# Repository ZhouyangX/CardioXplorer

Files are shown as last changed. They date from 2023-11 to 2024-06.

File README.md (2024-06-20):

# CardioXplorer: An Open-Source Catheter Robot

This repository contains open-source resources for a modular robotic system, designed for catheter ablation procedures, and validated by trainees and cardiologists. However, the modular design of the robot encourages the application of the system in various fields requiring the use of catheters.

Please make sure to reference or acknowledge the use of our repository if you find it useful!

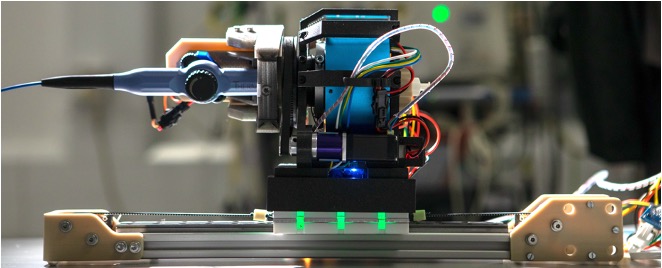
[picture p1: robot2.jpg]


## Overview

The robot is designed to manipulate commercial catheters in 3 degrees of freedom (DoF):
- Axial insertion/retraction
- Tool shaft rotation
- Catheter tip articulation

Independent actuators were employed for each DoF to enable flexible reconfiguration. The handle interface is easily customizable using silicone molds, thus able to accommodate various commercial catheters.

## Content

The repository contains:
- **CAD models** - 3D design files for mechanical parts.
- **Catheter Library** - 3D design files for 3 commercial catheter handles for ablation therapy and corresponding design files to develop silicone inserts for knob-based actuation module.
- **Software** - Control code, simulation (Blender Python API), data logger.
- **Media** - Photos and diagrams of the robot and the electronics.
- **Clincal Feedback** - Questionnaire and feedback results.

## Getting Started

To build the robot system:
1. 

| Part | Quantity | Estimated Cost |
| --- | --- | -- |
| PLA 3D Printer Filament | 1kg | $20 |
| PETG 3D Printer Filament | 50g | $5 |
| TPU 3D Printer Filament | 50g | $5 |
| Nema 17 Stepper Motor | 1 | $50 |
| Nema 8 Stepper Motor w/ 19:1 Gearbox | 1 | $50 |
| SAVOX SC-1251 MG 9kg Servo | 1kg | $50 |
| 6ch Through-hold Slip Ring | 1kg | $50 |
| 3mm Aluminum Plate | 1kg | $5 |
| 38.1mm OD Aluminum Pipe | 0.5m | $5 |
| WS2812B Addressable LEDs | 1m | $15 |
| 12V Electromagnets | 5 | $30 |
| Limit Switches | 2 | $2 |
| 20T GT2 Gears | 2 | $5 |
| 208T GT2 Close Loop Belt | 1 | $5 |
| GT2 Belt | 0.8m | $5 |
| Arduino MKR Zero | 4 | $130 |
| Arduino CAN Bus Shield | 4 | $130 |
| Arduino RS485 Shield | 2 | $50 |
| PS5 Controller | 1 | $30 |
| Mil-Max Pogo Connectors Pair | 1 | $5 |
| Hall Effect Sensor w/ Magnets | 1 | $10 |
| TMC5160 Stepper Motor Driver | 2 | $30 |
| **Estimated Total Cost:** | **-** | **$687** |

## Publications
The design and validation are described in the following publication:

Reference article - [https://doi.org/10.3390/robotics13050080](https://doi.org/10.3390/robotics13050080)

Xu, Z., Zeidan, A. M., He, Y., Leung, L., Byrne, C., Sabu, S., ... & Rhode, K. (2024). CardioXplorer: An Open-Source Modular Teleoperative Robotic Catheter Ablation System. Robotics, 13(5), 80.

## License
The contents of this repository are made available under the CC License. See LICENSE for details.

## Contributing
We welcome contributions - please submit pull requests!
See CONTRIBUTING for guidelines.

## Contact
Contact the team by email with any questions.

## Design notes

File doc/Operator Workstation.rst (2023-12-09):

Operator Workstation setup
======================

The operator workstation consist of two parts (MCU-based Controller and Display Unit).

MCU-Based Controller
--------------------------

This requires the installation of `Bluepad32 for Arduino <https://github.com/ricardoquesada/bluepad32-arduino>`_ firmware on the uBlox32 (or NINA) before uploading the Arduino code.

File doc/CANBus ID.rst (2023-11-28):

CANBus Message Table
======================

The CardioXplore uses a series of CANBus messages to communicate with other modules, all messages are sent at 1Mbps and with 8 bytes in each message.

CANBus Message Information
--------------------------
.. list-table::
   :widths: 25 50
   :header-rows: 1

   * - CANBus ID
     - Information
   * - 0x10
     - Joystick Controller
   * - 0x20
     - Railing Responder
   * - 0x30
     - Rotation Responder

Message Breakdown
------------------
.. list-table:: CANBus0x10
   :widths: 25 50
   :header-rows: 1

   * - Byte Position
     - Messages
   * - 0 
     - Left Joystick - X movement
   * - 1
     - Left Joystick - Y movement
   * - 2
     - Right Joystick - X movement
   * - 3
     - Right Joystick - Y movement
   * - 4
     - Right Joystick - R3 Button
   * - 5
     - L1 Button
   * - 6
     - R1 Button
   * - 7
     - Unassigned

.. list-table:: CANBus0x20
   :widths: 25 50
   :header-rows: 1

   * - Byte Position
     - Messages
   * - 0 - 3
     - Stepper Motor (NEMA17) Position
   * - 4
     - Unassigned
   * - 5
     - Unassigned
   * - 6
     - Unassigned
   * - 7
     - Unassigned

.. list-table:: CANBus0x30
   :widths: 25 50
   :header-rows: 1

   * - Byte Position
     - Messages
   * - 0 - 3
     - Stepper Motor (NEMA 8 w/ Gearbox) Position
   * - 4
     - Servo Position
   * - 5
     - Unassigned
   * - 6
     - Unassigned
   * - 7
     - Unassigned

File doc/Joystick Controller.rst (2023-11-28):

Controller Manager
==================

The CardioXplore comes with a set of predefined operations utilsing a PlayStaion 5 controller that allows the basic usage of the robot.

Front
-----

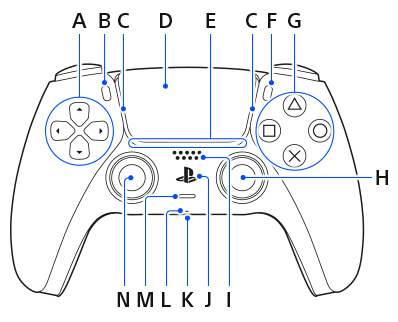
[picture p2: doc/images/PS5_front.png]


- A - Unassigned
- B - Long press with J to perform first-time pairing
- C - LED
    - Pulsing (Blue): pairing mode 
    - Solid (Blue): Connected
    - Solid (Orange): Charging
- D - Unassigned
- E - Unassigned
- F - Unassigned
- G - Unassigned (Will be used for Homing in the next generation)
- H - Right Joystick / R3
    - X movement (Left <--> Right): Tip Articulation
    - Y movement (Up <--> Down): Unassigned
    - R3: Short press to lock/unlock tip movement
- I - Unassigned
- J - Long press with B to perform first-time pairing
- K - Unassigned
- L - Unassigned
- M - Unassigned
- N - Left Joystick / L3
    - X movement (Left <--> Right): Handle Rotation
    - Y movement (Up <--> Down): Linear insertion/retraction
    - L3: Unassigned

Top
----

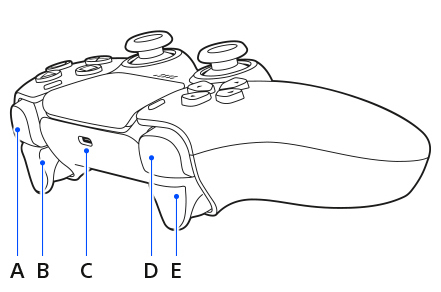
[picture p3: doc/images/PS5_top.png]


- A - Linear Lock (Press and hold to unlock, release to lock)
- B - Unassigned
- C - Charging port (Can be used while connected to a wall power supply)
- D - Rotation Lock (Press and hold to unlock, release to lock)
- E - Unassigned

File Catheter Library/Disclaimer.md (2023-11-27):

## Disclaimer
Biosense Webster ThermoCool SmartTouch SF Catheter and Biosense Webster CS Catheter with EZSteer are trademarks and/or registered trademarks of Medical Devices Business Services, Inc., Biosense Webster, Inc., and Johnson & Johnson Medical Limited.

Boston Scientific Blazer II XP is trademarks and/or registered trademarks of Boston Scientific Corporation. 

This information is intended for research purposes only and does not provide specific legal or regulatory advice. Ask your healthcare provider about whether a device is right for you and the associated risks and benefits.

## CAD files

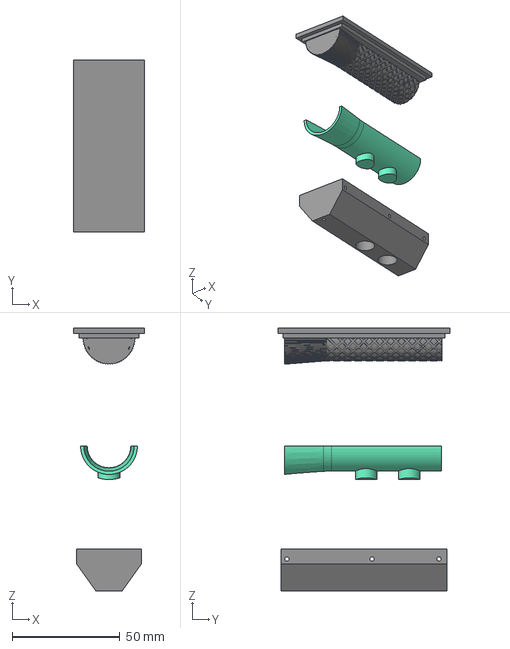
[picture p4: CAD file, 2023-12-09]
Knob Based Catheter Module/Biosense Webster SmartTouch SF/Biosense Webster Silicone Mold.step
32.8 x 79.8 x 121.9 mm

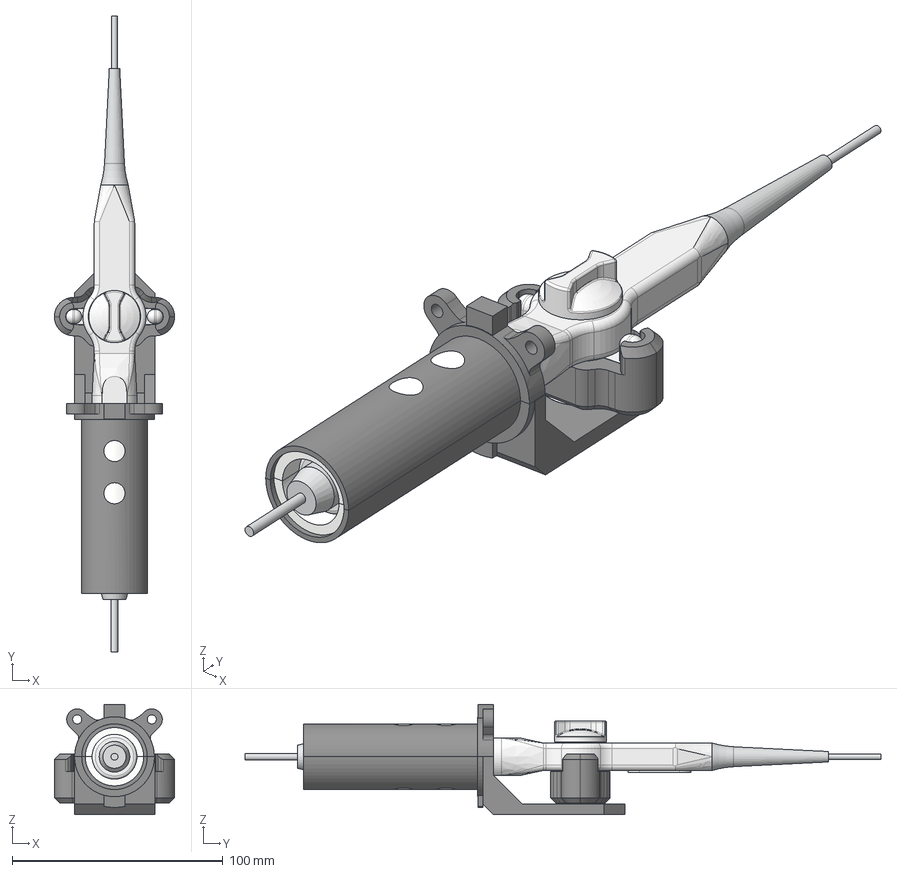
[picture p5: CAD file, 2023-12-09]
Knob Based Catheter Module/Boston Scientific Blazer II XP/Blazer II XP Caddy.step
57.0 x 301.5 x 52.4 mm
Silicone Insert
Upper
Lower
6802RS
Mini Platform
Blazer II XP_1
Knob Carrier v1 (1)

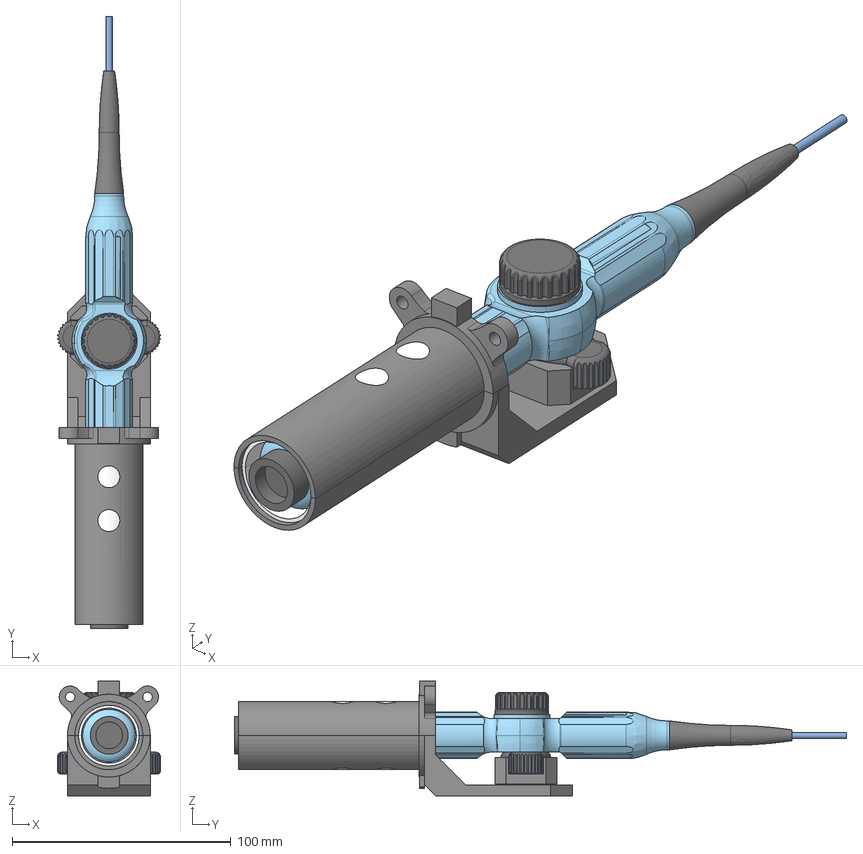
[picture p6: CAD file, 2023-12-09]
Knob Based Catheter Module/Biosense Webster SmartTouch SF/Biosense Webster SmartTouch SF.step
47.0 x 279.5 x 52.4 mm
Silicone Insert
Upper
Lower
6802RS
Mini Platform
Knob Carrier v1
Biosense Webster Smart Touch New

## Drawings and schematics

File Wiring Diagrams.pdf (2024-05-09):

## RAILING RESPONDER

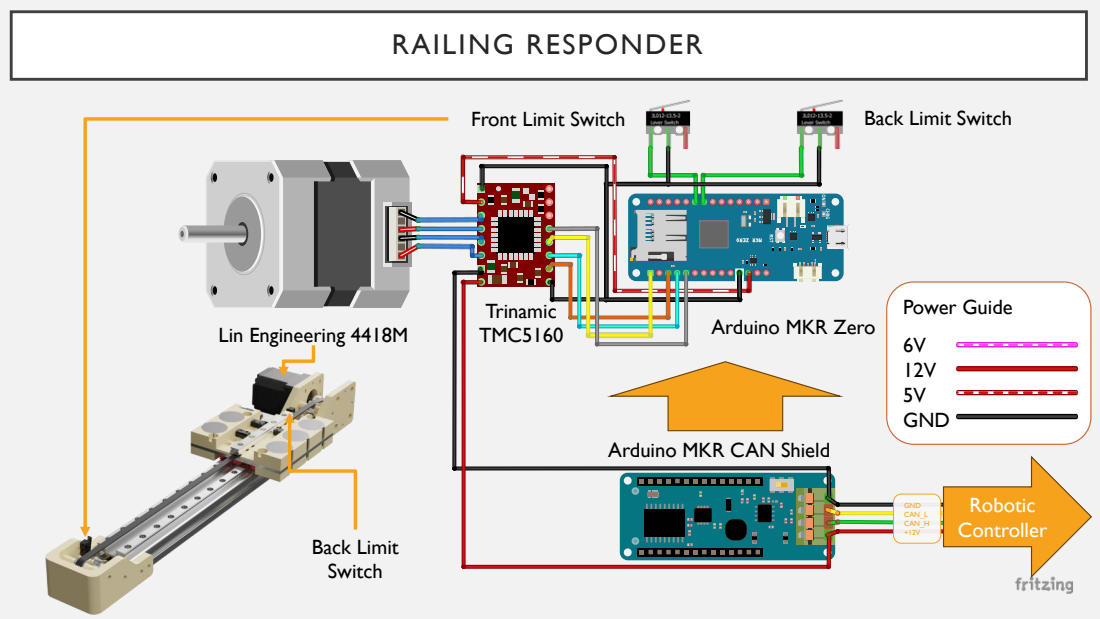
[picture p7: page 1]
Lin Engineering 4418M; Trinamic; TMC5160; Arduino MKR Zero; Robotic Controller; Power Guide; 6V 12V 5V GND; GND CAN_L CAN_H +12V; Front Limit Switch; Back Limit Switch

Arduino MKR CAN Shield

## PLATFORM RESPONDER

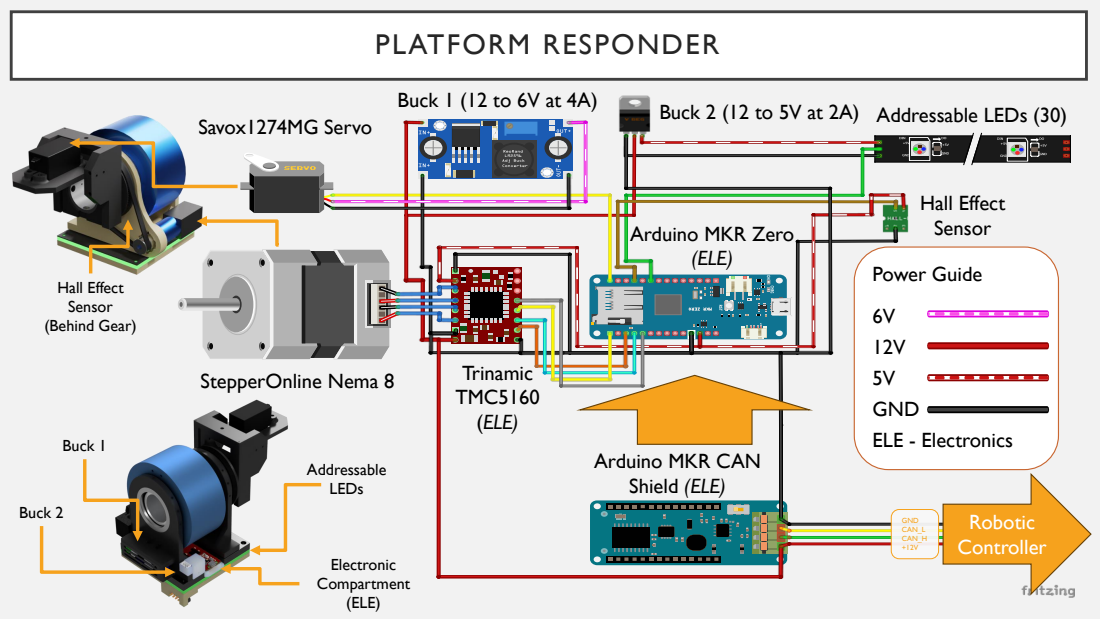
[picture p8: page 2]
StepperOnline Nema 8; Trinamic TMC5160 (ELE); (ELE); Robotic Controller; Power Guide; GND; ELE - Electronics; GND CAN_L CAN_H +12V; Hall Effect Sensor; Savox1274MG Servo; Buck 1 (12 to 6V at 4A); Buck 2 (12 to 5V at 2A) Addressable LEDs (30); Hall Effect Sensor (Behind Gear); Buck 1; Buck 2; Electronic Compartment (ELE); Addressable LEDs

Arduino MKR Zero

Arduino MKR CAN
Shield (ELE)

## MAIN ROBOTIC CONTROLLER

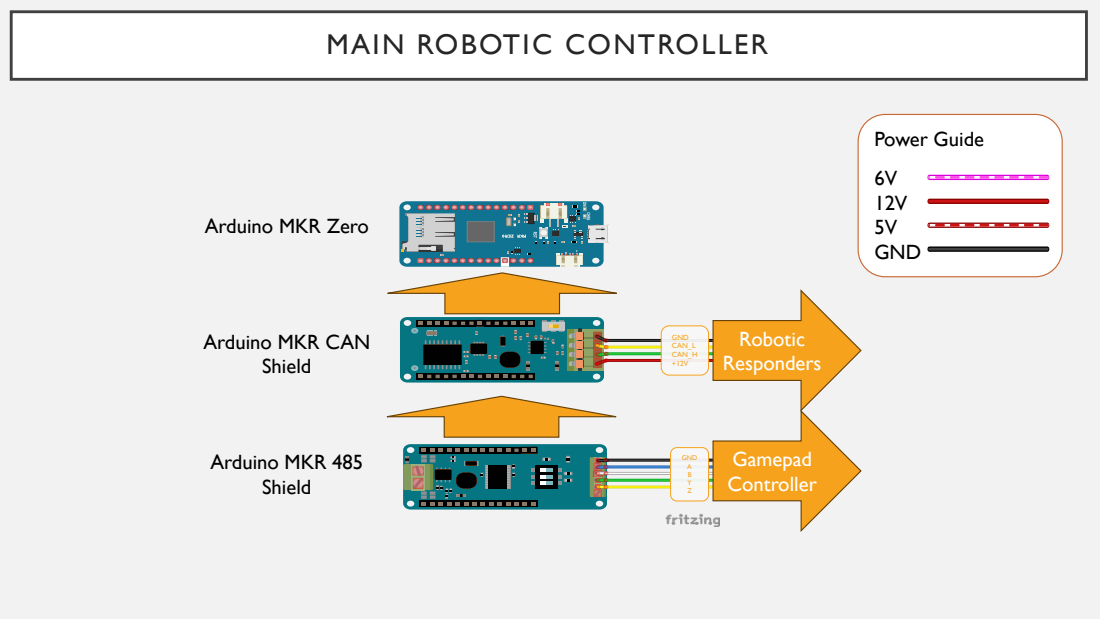
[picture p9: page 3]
Arduino MKR 485 Shield; Robotic Responders; Power Guide; 6V 12V 5V GND; GND CAN_L CAN_H +12V; Shield; Gamepad Controller; GND A B Y Z

Arduino MKR Zero

Arduino MKR CAN

## GAMEPAD CONTROLLER

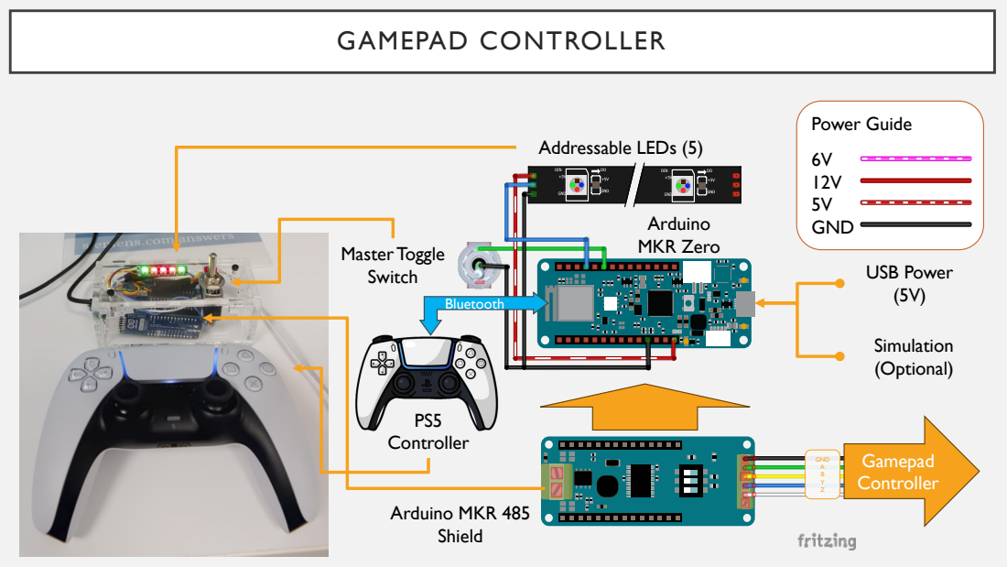
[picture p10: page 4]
Arduino MKR 485 Shield; Power Guide; Arduino; GND; MKR Zero; Gamepad Controller; GND A B Y Z; Master Toggle Switch; Addressable LEDs (5); USB Power (5V); Simulation (Optional); PS5 Controller; Bluetooth

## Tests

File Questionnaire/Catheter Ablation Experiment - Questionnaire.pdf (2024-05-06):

## Evaluating CardioXplorer: A Robotic Catheter Ablation System Questionnaire

Thank you for participating in this robotic left atrial catheter ablation experiment. Kindly take a few moments to provide us with your valuable feedback by completing the following questionnaire. Your input will help us improve the system and better understand its usability and effectiveness.

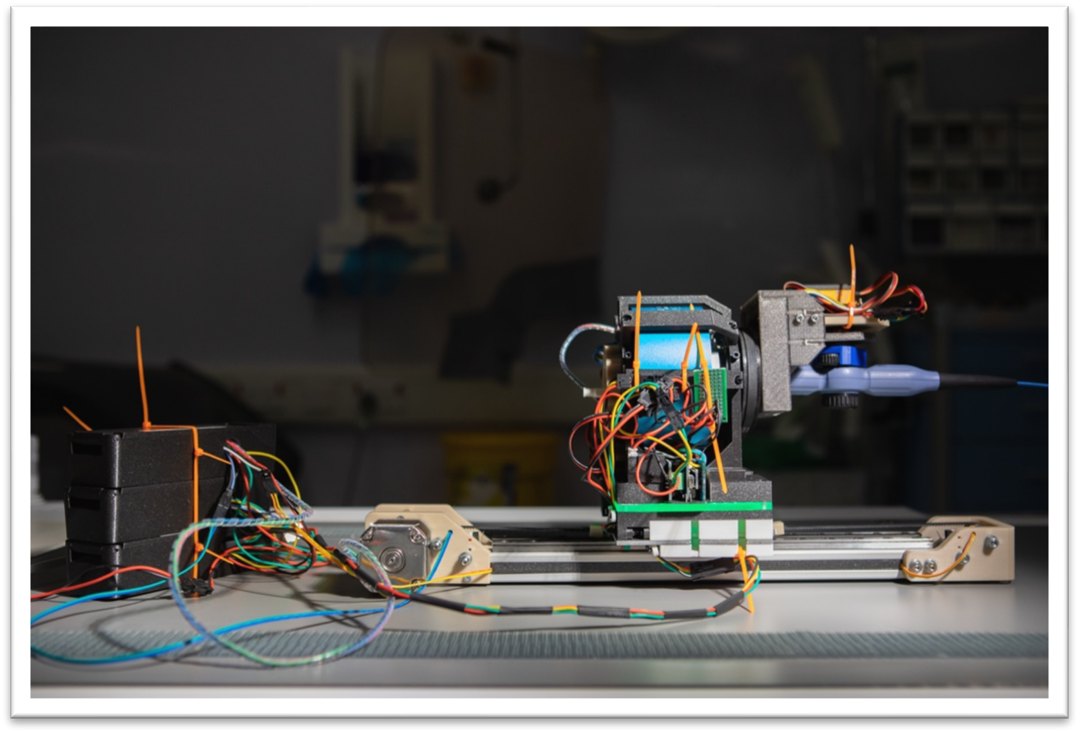
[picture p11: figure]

General Information

- Name: _________________________________________________________________
- Years of experience as a cardiologist: _________________________________________

Page 2 | 6

Section 1: General Questions about Catheter Ablation Procedures
The purpose of this section is to understand your approach to catheter ablation. It is just for our general knowledge.
1. Are there instances where you don’t use PVI, and you use another technique instead? ________________________________________________________________________ ________________________________________________________________________ ________________________________________________________________________ ________________________________________________________________________ ________________________________________________________________________ ________________________________________________________________________ ________________________________________________________________________ ________________________________________________________________________ ________________________________________________________________________
2. What are the most common factors for AF re-occurrence (e.g., gaps between ablation points)?
________________________________________________________________________ ________________________________________________________________________ ________________________________________________________________________ ________________________________________________________________________ ________________________________________________________________________ ________________________________________________________________________ ________________________________________________________________________ ________________________________________________________________________ ________________________________________________________________________
3. During repeat ablation, because of AF re-occurrence, what factors determine your choice of treatment?
________________________________________________________________________ ________________________________________________________________________ ________________________________________________________________________ ________________________________________________________________________ ________________________________________________________________________ ________________________________________________________________________ ________________________________________________________________________ ________________________________________________________________________ ________________________________________________________________________

Page 3 | 6
4. What are the top three parameters you look out for during ablation? ________________________________________________________________________ ________________________________________________________________________ ________________________________________________________________________ ________________________________________________________________________ ________________________________________________________________________ ________________________________________________________________________ ________________________________________________________________________ ________________________________________________________________________ ________________________________________________________________________

Page 4 | 6

Section 2: Robotic System Evaluation
Please rate the following aspects of the robotic system, using a scale of 1 to 5: (1 = strongly disagree/very unsatisfied/very poor, 2 = disagree/unsatisfied/poor, 3 = neutral/fair, 4 = agree/satisfied/good, 5 = strongly agree/very satisfied/excellent). Strongly Disagree

Disagree
Neutral
Agree

Strongly
Agree
1. The system is easy to use. | 1 | 2 | 3 | 4 | 5
2. The system provides all the motions required to
perform ablation. | 1 | 2 | 3 | 4 | 5
3. The system was reliable and consistent during the
procedure. | 1 | 2 | 3 | 4 | 5
4. The system easily integrates with existing equipment
in the X-MRI lab. | 1 | 2 | 3 | 4 | 5
5. The visual feedback, such as the LEDs, simulation,
and video feedback, provide sufficient information
on what is happening inside the lab. | 1 | 2 | 3 | 4 | 5
6. The simulation of the robot alone, provides
sufficient information on what is happening inside
the lab. | 1 | 2 | 3 | 4 | 5
7. The video feedback from the camera, provides
sufficient information on what is happening inside
the lab. | 1 | 2 | 3 | 4 | 5
8. There were no limitations or challenges
encountered during the procedure. | 1 | 2 | 3 | 4 | 5

Page 5 | 6

Section 3: Catheter Ablation Maneuvers
Please rate the following aspects of the maneuvers provided by the robotic system to perform ablation in terms of speed and sensitivity, using a scale of 1 to 5.
- Speed:
- Speed here refers to how quickly and efficiently the catheter ablation maneuvers can be performed. Participants are being asked to rate the ease and efficiency with which they can execute these maneuvers within a specific time frame.
- A higher rating for speed might indicate that participants find the maneuvers to be easily and quickly executable without unnecessary delays or complications.
- This dimension assesses the procedural efficiency, time management, and the smoothness of performing the maneuvers.
- Sensitivity:
- Sensitivity in this context refers to how delicately and accurately the catheter ablation maneuvers need to be performed. Participants are being asked to rate the level of precision and attention to detail required for each maneuver.
- A higher sensitivity rating might indicate that participants recognize the need for careful and accurate execution, where even slight variations can have significant consequences.
- This dimension assesses the precision, accuracy, and intricacy demanded by the maneuvers.
Speed | Sensitivity

Strongly Disagree
Disagree
Neutral
Agree

Strongly Agree

Strongly Disagree
| Disagree Neutral Agree

Strongly Agree

1. Insertion.
| 1 | 2 | 3 | 4 | 5 | 1 | 2 | 3 | 4 | 5
2. Advancement.
| 1 | 2 | 3 | 4 | 5 | 1 | 2 | 3 | 4 | 5
3. Handle rotation.
| 1 | 2 | 3 | 4 | 5 | 1 | 2 | 3 | 4 | 5
4. Catheter tip flexion and
extension. | 1 | 2 | 3 | 4 | 5 | 1 | 2 | 3 | 4 | 5
5. Steering. | 1 | 2 | 3 | 4 | 5 | 1 | 2 | 3 | 4 | 5
6. Withdrawal. | 1 | 2 | 3 | 4 | 5 | 1 | 2 | 3 | 4 | 5

Page 6 | 6

Section 4: Joystick Controller
Please rate the following aspects of the joystick controller, using a scale of 1 to 5: (1 = strongly disagree/very unsatisfied/very poor, 2 = disagree/unsatisfied/poor, 3 = neutral/fair, 4 = agree/satisfied/good, 5 = strongly agree/very satisfied/excellent). Strongly Disagree

Disagree
Neutral
Agree

Strongly
Agree
1. The interaction with the robot is natural, i.e., left hand for linear translation, both hands for rotation,
and right hand for tip deflection.
1 | 2 | 3 | 4 | 5
2. The joystick controller provides intuitive control. | 1 | 2 | 3 | 4 | 5
3. The joystick interface is easy to navigate. | 1 | 2 | 3 | 4 | 5
4. The joystick controller is comfortable to hold during
the procedure. | 1 | 2 | 3 | 4 | 5
5. The joystick is responsive. | 1 | 2 | 3 | 4 | 5

Section 5: Additional Feedback
We value your suggestions and ideas for improving the robotic system. Please share any feedback, recommendations, or features you would like to see in future iterations. ______________________________________________________________________________ ______________________________________________________________________________ ______________________________________________________________________________ ______________________________________________________________________________ ______________________________________________________________________________ ______________________________________________________________________________ ______________________________________________________________________________ ______________________________________________________________________________ ______________________________________________________________________________

Thank you for your participation and valuable feedback. Your input will contribute to the advancement and refinement of our robotic system for left atrial catheter ablation.

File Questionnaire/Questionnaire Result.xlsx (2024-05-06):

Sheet: System Evaluation
 | Participant 1 | Participant 2 | Participant 3 | Participant 4 | Participant 5 | Mean | STD
The system is easy to use. | 2 | 4 | 4 | 5 | 4 | 3.8 | 1.1
The system provides all the motions required to perform ablation. | 3 | 4 | 4 | 5 | 4 | 4 | 0.7
The system was reliable and consistent during the procedure. | 3 | 4 | 4 | 5 | 5 | 4.2 | 0.8
The system easily integrates with existing equipment in the X-MRI lab. | 4 | 3 | 4 | 5 | 5 | 4.2 | 0.8
The visual feedback, such as the LEDs, simulation, and video feedback, provide sufficient information on what is happening inside the lab. | 3 | 4 | 4 | 4 | 5 | 4 | 0.7
The simulation of the robot alone, provides sufficient information on what is happening inside the lab. | 2 | 3 | 4 | 4 | 4 | 3.4 | 0.9
The video feedback from the camera, provides sufficient information on what is happening inside the lab. | 3 | 3 | 4 | 3 | 5 | 3.6 | 0.9
There were no limitations or challenges encountered during the procedure. | 1 | 4 | 4 | 3 | 4 | 3.2 | 1.3
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

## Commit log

2023-11-28 Create CANBus ID.rst
2023-11-28 Update CANBus ID.rst
